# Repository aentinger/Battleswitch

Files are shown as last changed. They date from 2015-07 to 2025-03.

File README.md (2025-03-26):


💾 Battleswitch
===============



# 📸 Image

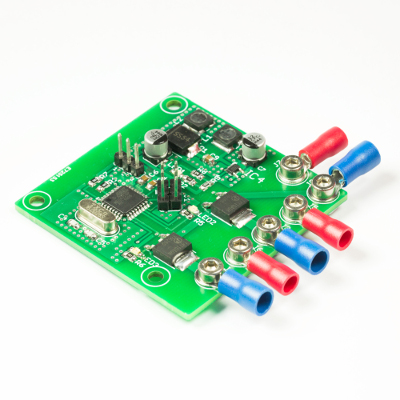
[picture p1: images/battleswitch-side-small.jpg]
LXRobotics P18 Battleswitch


# 📂 Description

A battleswitch is an electronic module which is responsible for the activation/deactivation of weapon systems in combat robots. More generally spoken, a battleswitch is a module which enables the switching of loads using an ordinary remote control.

The LXRobotics Battleswitch enables the control of up to 2 actuators over a single RC remote control channel. The battleswitch is connected to and powered by the RC receiver over a 3-pin connection like a servo and tolerates a wide input voltage range from 2 to 8 V DC with a maximum current consumption of 75 mA. The internal software state of the battleswitch is visualized via LEDs, which greatly simplifies operation and integration of the battleswitch. The assignment which remote control input signal leads to which actuator output, is performed via firmware versions which are generated by LXRobotics upon request.

**Features**

* 1 Remote control channel switches 2 actuators
* Switching capacity per channel: max. 40 V / 5 A @ 100 °C
* Supply of the battleswitch electronics by the RC receiver - no additional power supply terminal necessary
* Wide input voltage range for electronic supply: 2 - 8 V DC
* Status-LEDs signal the internal software state and the current switching status
* POWER-LED lights up when there the battleswitch is supplied with power
* Failsafe - switching off the actuators in the absence of a valid remote control signal
* Freewheeling diodes available - switching of inductive loads possible
* 3 x M3 holes for stable mounting of the Battleswitch
* Small size: 50 x 50 mm (L x W)

# 🎥 [Video](images/battleswitch_demo.mp4)

# 💻 Build
```bash
sudo apt-get install cmake avr-libc binutils-avr gcc-avr avrdude
git clone https://github.com/aentinger/Battleswitch && cd Battleswitch/software
mkdir build && cd build
cmake ..
make
```

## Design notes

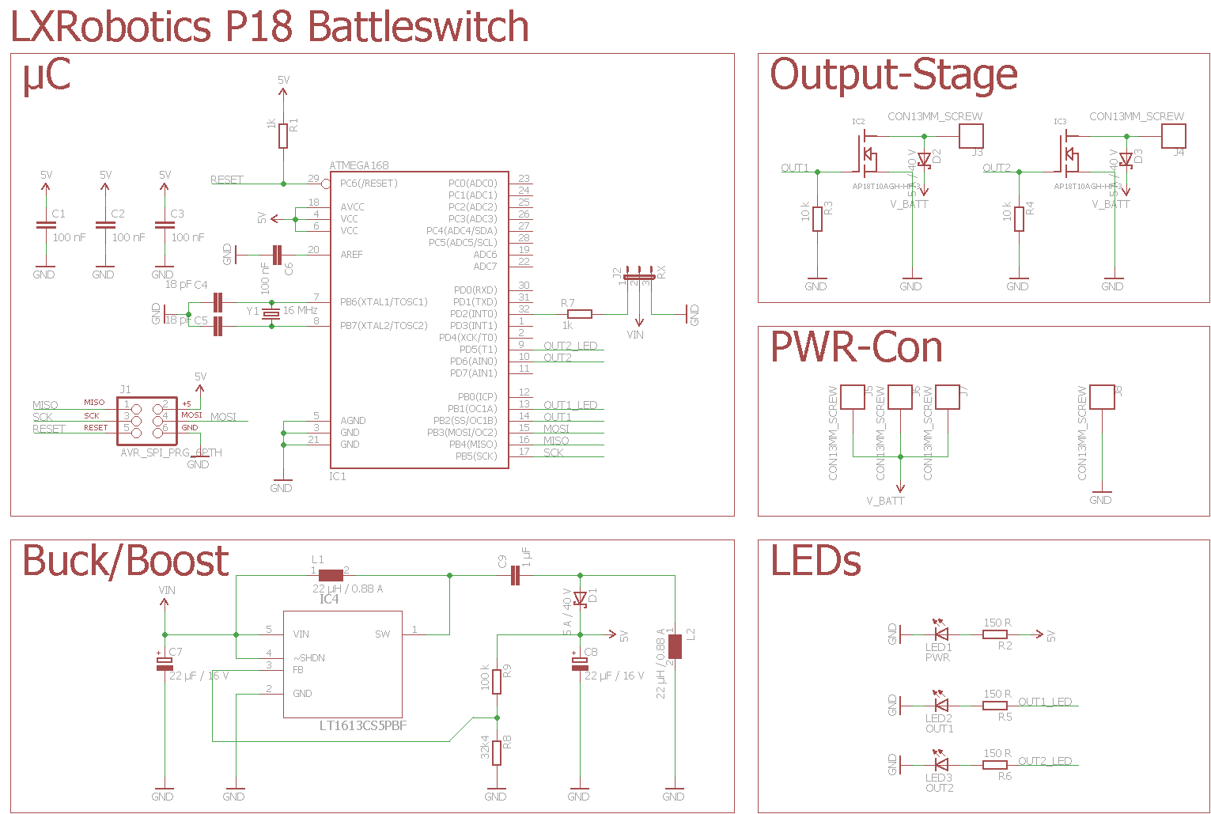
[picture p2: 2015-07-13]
hardware/lxr_battleswitch_v1.png

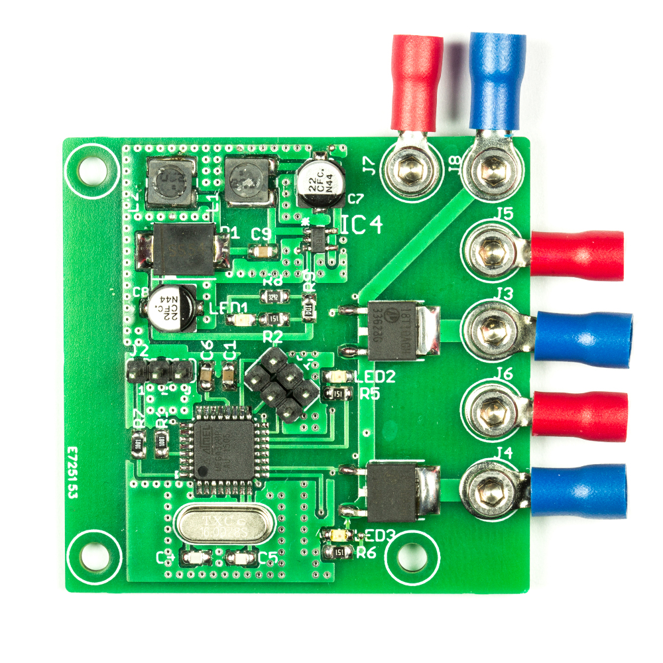
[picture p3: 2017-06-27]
images/battleswitch-top-large.jpg

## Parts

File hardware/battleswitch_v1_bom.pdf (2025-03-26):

Menge | Schaltplan | Bezeichnung | Farnell/Conrad Bestell Nummer | Preis (1 Stück) | Gesamtpreis | Wird bestückt | Footprint | Säckchen
4 | C1-C3,C6 | Kondensator, 100 nF, 16 V, 0805 | 1759144 | € 0,01 | € 0,04 | X
2 | R1,R7 | Widerstand, 1k, 0805 | 1469847 | € 0,02 | € 0,05 | X
1 | IC1 | ATMEGA328P-AUR, TQFP32 | 2425124 | € 2,50 | € 2,50 | X
1 | Y1 | Quarz, 16 MHz, HC49S | 1842216 | € 0,39 | € 0,39 | X
2 | C4,C5 | Kondensator, 18 pF, 100 V, 0805 | 1740651 | € 0,08 | € 0,16 | X
1 | J1 | Stiftleiste, 2x3, 2.54 mm | 1022226 | € 0,39 | € 0,39 | X
3 | LED1-LED3 | SMD-LED, Grün, 0805, If=20 mA, Uf=2.1 | 1519498 | € 0,24 | € 0,72 | X
3 | R2,R5,R6 | Widerstand, 150 R, 0805 | 9333916 | € 0,01 | € 0,02 | X
2 | IC2,IC3 | AP18T10AGH-HF-3TR, N-Kanal-MOSFET, TO-252 | 2319588 | € 0,64 | € 1,28 | X
2 | R3,R4 | Widerstand, 10k, 0805 | 1469856 | € 0,02 | € 0,04 | X
1 | J2 | Stiftleiste, 1x3, 2.54 mm | 1022249 | € 0,07 | € 0,07 | X
1 | IC4 | LT1613CS5 Buck/Boost-Converter | 2115857 | € 2,66 | € 2,66 | X
2 | C7,C8 | 22 µF, 16 V, Panasonic C | 9694366 | € 0,25 | € 0,51 | X
2 | L1,L2 | 22 µF, 0.88 A | 1635843 | € 1,36 | € 2,72 | X
3 | D1-D3 | Diode, 5A, 40 V | 1861427 | € 0,17 | € 0,50 | X
1 | R8 | 32k4, 0805, 0.1 % | 1575962 | € 0,12 | € 0,12 | X
1 | R9 | 100k, 0805, 0.1 % | 1577686 | € 0,06 | € 0,06 | X
1 | C9 | 1 µF / 25 V / 0805 | 9406395 | € 0,09 | € 0,09 | X
6 | J3-J8 | Ringkabelschuh, M3 | 745501 - 62 / 746087 - 62 | € | - | X | Conrad Elektronik
Summe | € | 12,32

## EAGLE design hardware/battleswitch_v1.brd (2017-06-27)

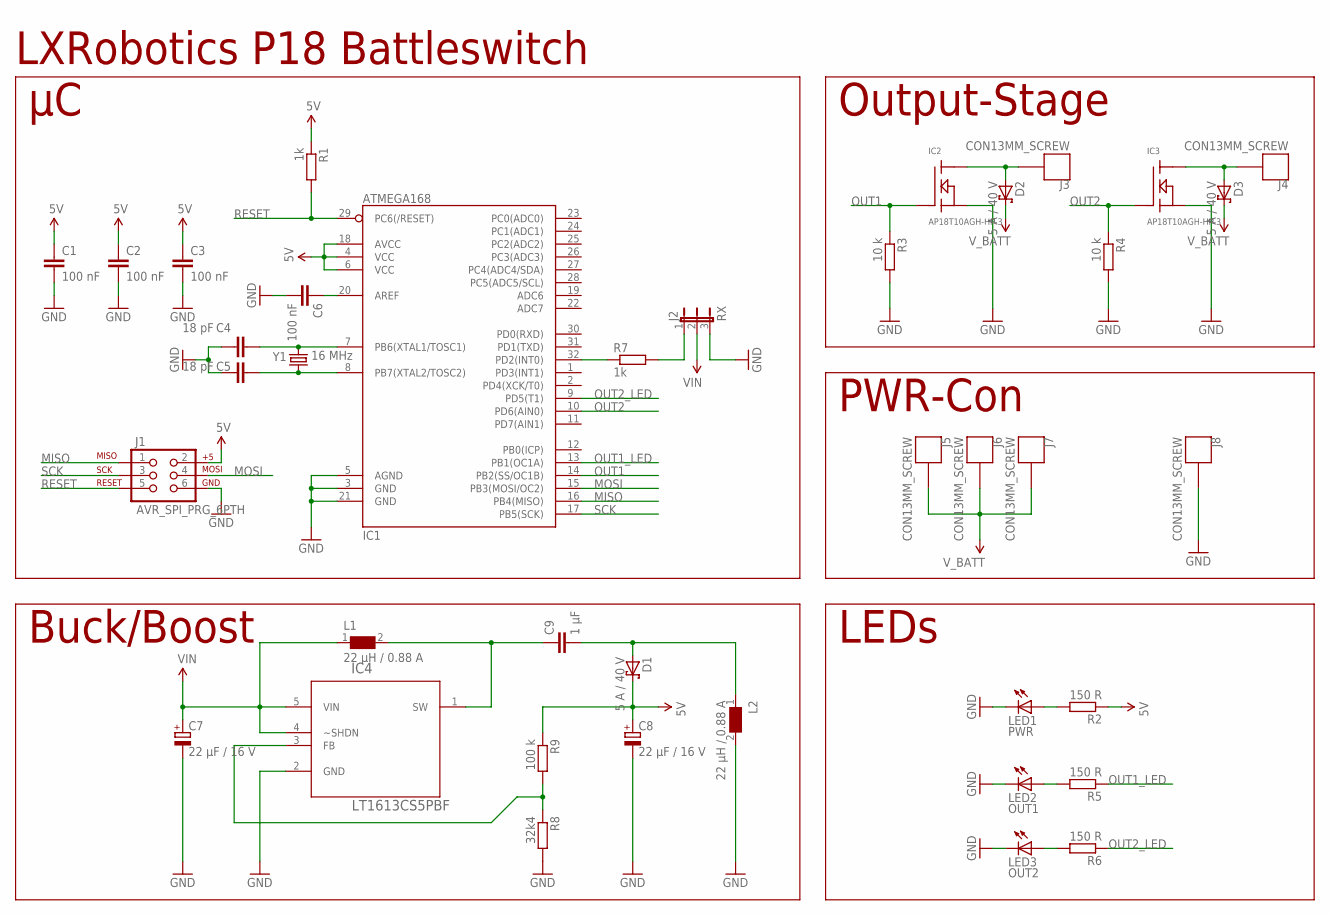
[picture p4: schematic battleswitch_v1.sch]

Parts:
C1, C2, C3, C6: 100 nF; C0805
C4, C5: 18 pF; C0805
C7, C8: 22 µF / 16 V; PANASONIC_C
C9: 1 µF; C0805
D1, D2, D3: 5 A / 40 V; SMC
IC1: ATMEGA168; TQFP32-08
IC2, IC3: AP18T10AGH-HF-3; TO252
IC4: LT1613CS5PBF; SOT95P280X145-5N
J1: AVR_SPI_PRG_6PTH; 2X3
J2: RX; JP2
J3, J4, J5, J6, J7, J8: CON13MM_SCREW; CON1_3MM_SCREW
L1, L2: 22 µH / 0.88 A; WE-TPC_4818/4828
LED1: PWR; CHIP-LED0805
LED2: OUT1; CHIP-LED0805
LED3: OUT2; CHIP-LED0805
R1, R7: 1k; R0805
R2, R5, R6: 150 R; R0805
R3, R4: 10 k; R0805
R8: 32k4; R0805
R9: 100 k; R0805
Y1: 16 MHz; HC49US

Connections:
5V: C1.1, C2.1, C3.1, C8.+, D1.C, IC1.4 (VCC), IC1.6 (VCC), IC1.18 (AVCC), J1.2, R1.1, R2.1, R9.1
GND: C1.2, C2.2, C3.2, C4.2, C5.2, C6.2, C7.-, C8.-, IC1.3 (GND), IC1.5 (AGND), IC1.21 (GND), IC2.S, IC3.S, IC4.2 (GND), J1.6, J2.3, J8.P$1, L2.2, LED1.C, LED2.C, LED3.C, R3.2, R4.2, R8.2
MISO: IC1.16 (PB4(MISO)), J1.1
MOSI: IC1.15 (PB3(MOSI/OC2)), J1.4
unnamed: J2.1, R7.2
unnamed: C6.1, IC1.20 (AREF)
unnamed: IC1.32 (PD2(INT0)), R7.1
unnamed: LED2.A, R5.2
unnamed: LED3.A, R6.2
unnamed: D2.A, IC2.D, J3.P$1
unnamed: D3.A, IC3.D, J4.P$1
unnamed: C9.1, IC4.1 (SW), L1.2
unnamed: IC4.3 (FB), R8.1, R9.2
unnamed: C9.2, D1.A, L2.1
unnamed: C4.1, IC1.7 (PB6(XTAL1/TOSC1)), Y1.2
unnamed: C5.1, IC1.8 (PB7(XTAL2/TOSC2)), Y1.1
unnamed: LED1.A, R2.2
OUT1: IC1.14 (PB2(SS/OC1B)), IC2.G, R3.1
OUT1_LED: IC1.13 (PB1(OC1A)), R5.1
OUT2: IC1.10 (PD6(AIN0)), IC3.G, R4.1
OUT2_LED: IC1.9 (PD5(T1)), R6.1
RESET: IC1.29 (PC6(/RESET)), J1.5, R1.2
SCK: IC1.17 (PB5(SCK)), J1.3
VIN: C7.+, IC4.4 (~SHDN), IC4.5 (VIN), J2.2, L1.1
V_BATT: D2.C, D3.C, J5.P$1, J6.P$1, J7.P$1

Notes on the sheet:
Output-Stage
PWR-Con
LEDs
Buck/Boost
LXRobotics P18 Battleswitch

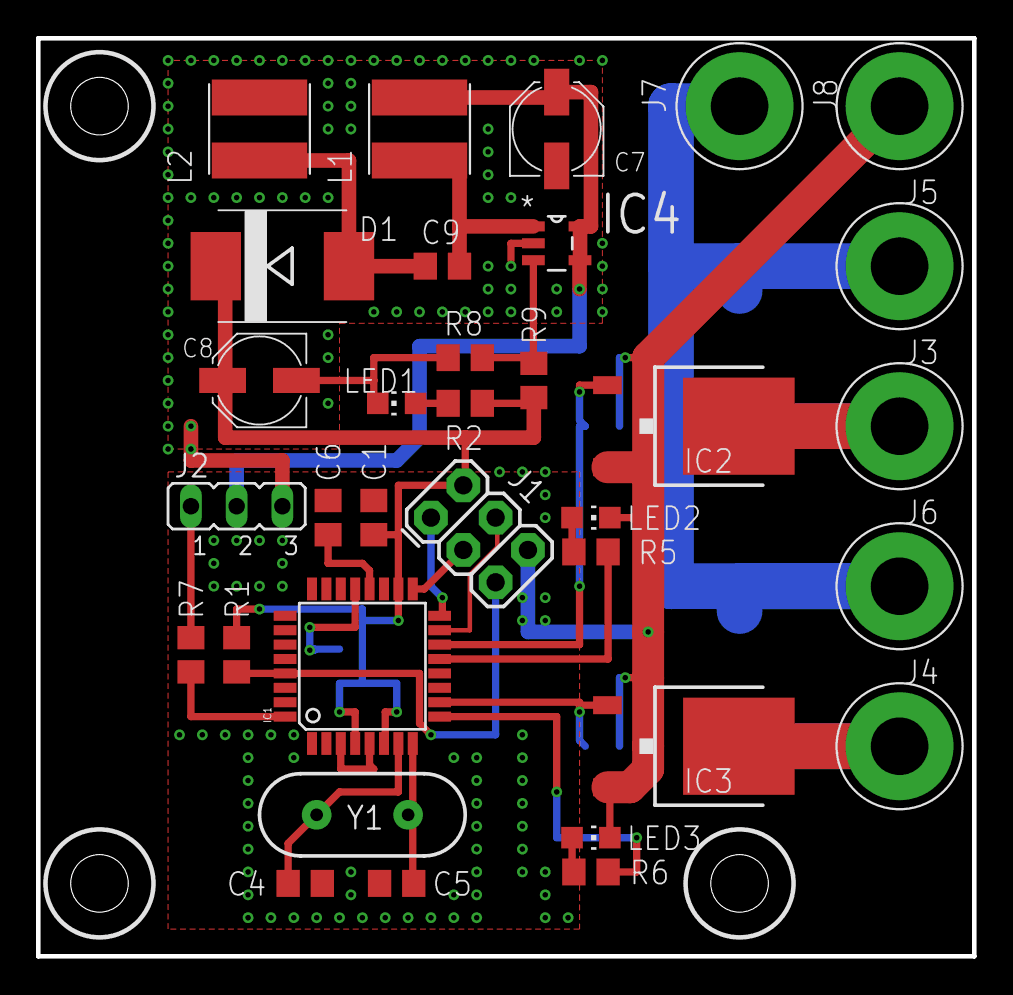
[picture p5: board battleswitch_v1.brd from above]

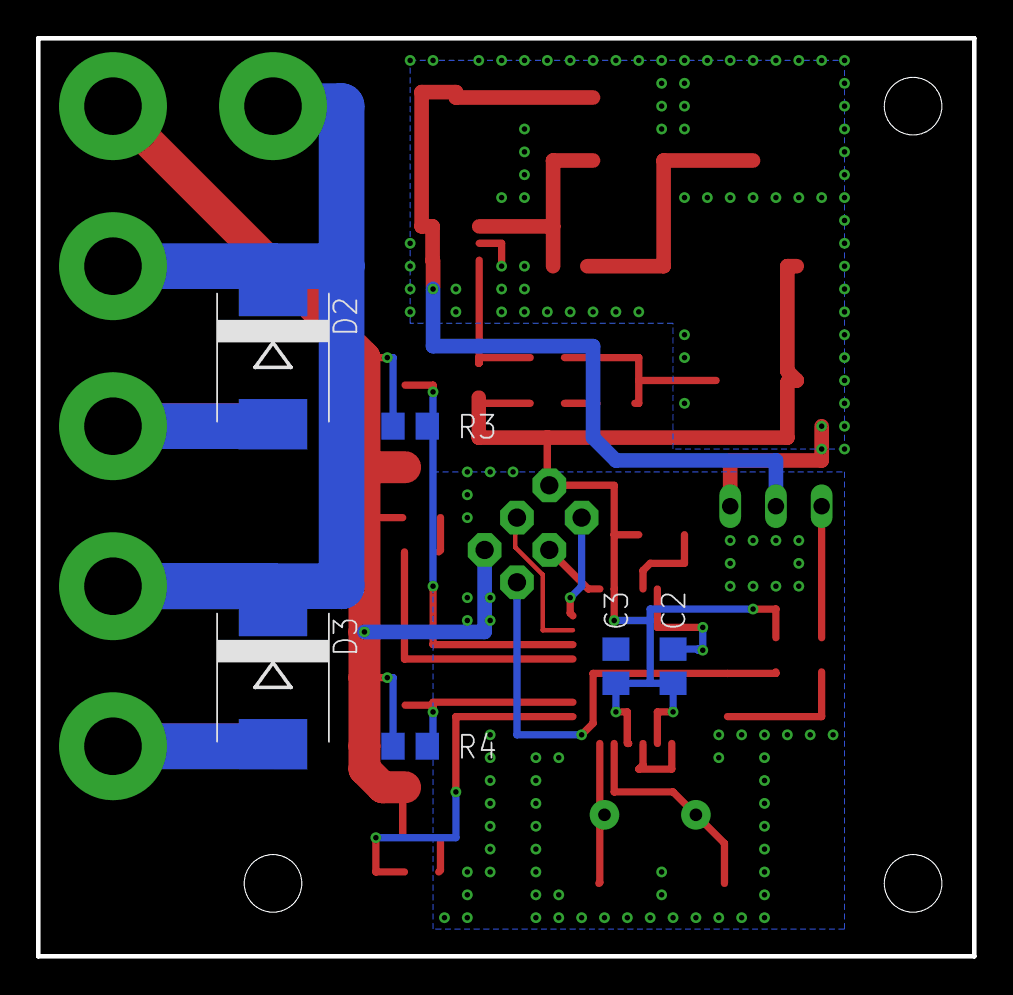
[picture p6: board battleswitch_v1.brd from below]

Board: 2 copper layers, 52.0 x 51.0 mm, 39 parts (6 on the bottom side), 25 nets.

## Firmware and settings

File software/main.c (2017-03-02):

/** 
 * @author Alexander Entinger, MSc / LXRobotics
 * @brief main file for the battleswitch software
 * @file main.c
 * @license
 */

/* INCLUDES */

#include <stdint.h>
#include <stdbool.h>

#include <avr/io.h>
#include <util/delay.h>
#include <avr/interrupt.h>

#include "rc_input.h"
#include "led_control.h"
#include "switch_control.h"

/* PROTOTYPES */

/** 
 * @brief initializes the application
 */
void init_application();

/* FUNCTIONS */

int main(void)
{
	typedef enum {INIT = 0, WAIT_FOR_SIGNAL = 1, ACTIVE = 2} E_BATTLESWITCH_STATE;
	E_BATTLESWITCH_STATE state = INIT;
	
	for(;;)
    {
        switch(state)
		{
		case INIT:
		{
			// call the initialize function
			init_application();
			
			// show init complete via led
			led_control_set_led(LED_OUT_1, LED_ON);
			led_control_set_led(LED_OUT_2, LED_ON);
			_delay_ms(1000);
			led_control_set_led(LED_OUT_1, LED_OFF);
			led_control_set_led(LED_OUT_2, LED_OFF);
			_delay_ms(1000);
			
			// switch to next state
			state = WAIT_FOR_SIGNAL;			
		}	
		break;
		case WAIT_FOR_SIGNAL:
		{
			// toogle leds to show we are waiting for a receiver signal
			static bool led_out_1_on = true;
			if(led_out_1_on)
			{
				led_control_set_led(LED_OUT_1, LED_ON);	
				led_control_set_led(LED_OUT_2, LED_OFF);
			}
			else
			{
				led_control_set_led(LED_OUT_1, LED_OFF);
				led_control_set_led(LED_OUT_2, LED_ON);				
			}
			led_out_1_on = !led_out_1_on;
			_delay_ms(100);
			
			// check if we have a stable signal (and if we have, transition to the active mode)
			if(rc_input_is_channel_good())
			{
				// turn leds off ... 
				led_control_set_led(LED_OUT_1, LED_OFF);
				led_control_set_led(LED_OUT_2, LED_OFF);
				
				// ... and switch to active state
				state = ACTIVE;
			}			
		}
		break;
		case ACTIVE:
		{
			if(rc_input_is_channel_good())
			{
				uint16_t const current_pulse_duration_us = rc_input_get_pulse_width_us();
				
				if(current_pulse_duration_us > 1750)
				{
					switch_control_set_switch(OUT_1, SWITCH_ON);
					
					led_control_set_led(LED_OUT_1, LED_ON);
				}
				else if(current_pulse_duration_us < 1250)
				{
					switch_control_set_switch(OUT_1, SWITCH_ON);
					switch_control_set_switch(OUT_2, SWITCH_ON);
					
					led_control_set_led(LED_OUT_1, LED_ON);
					led_control_set_led(LED_OUT_2, LED_ON);
				}
				else
				{
					switch_control_set_switch(OUT_1, SWITCH_OFF);
					switch_control_set_switch(OUT_2, SWITCH_OFF);
					
					led_control_set_led(LED_OUT_1, LED_OFF);
					led_control_set_led(LED_OUT_2, LED_OFF);
				}				
			}
			else
			{
				// turn outputs off ...
				switch_control_set_switch(OUT_1, SWITCH_OFF);
				switch_control_set_switch(OUT_2, SWITCH_OFF);
				
				// ... turn leds off ...
				led_control_set_led(LED_OUT_1, LED_OFF);
				led_control_set_led(LED_OUT_2, LED_OFF);
				
				// ... and fall back in the waiting for signal state 				
				state = WAIT_FOR_SIGNAL;
			}
		}
		break;
		default: break;
		}
    }
}


/** 
 * @brief initializes the application
 */
void init_application()
{
	// initializes led control
	led_control_init();
	
	// initialize switch control
	switch_control_init();
	
	// initialize the rc input unit
	rc_input_init();
	
	// globally enable interrupts
	sei();
}

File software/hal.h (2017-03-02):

/** 
 * @author Alexander Entinger, MSc / LXRobotics
 * @brief hardware abstraction layer file contains all definitions for the i/o ports of the battleswitch
 * @file hal.h
 * @license
 */

#ifndef HAL_H_
#define HAL_H_

/* INCLUDES */

#include <avr/io.h>

/* DEFINES */

// LED's

#define LED_OUT_1_DDR		DDRB
#define LED_OUT_1_PORT		PORTB
#define LED_OUT_1_bm		(1<<PORTB1)

#define LED_OUT_2_DDR		DDRD
#define LED_OUT_2_PORT		PORTD
#define LED_OUT_2_bm		(1<<PORTD5)

// MOSFET's

#define OUT_1_DDR			DDRB
#define OUT_1_PORT			PORTB
#define OUT_1_bm			(1<<PORTB2)

#define OUT_2_DDR			DDRD
#define OUT_2_PORT			PORTD
#define OUT_2_bm			(1<<PORTD6)

// RC INPUT

#define RC_DDR				DDRD
#define RC_PORT				PORTD
#define RC_bm				(1<<PORTD2)

#endif /* HAL_H_ */

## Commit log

2017-06-27 Adding hardware + images
    [battleswitch_v1.brd, battleswitch_v1.sch]
2025-03-26 Add BOM.

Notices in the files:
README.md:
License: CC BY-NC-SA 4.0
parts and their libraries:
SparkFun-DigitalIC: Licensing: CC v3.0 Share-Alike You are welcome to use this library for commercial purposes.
